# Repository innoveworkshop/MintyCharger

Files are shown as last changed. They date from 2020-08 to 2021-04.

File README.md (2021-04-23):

# MintyCharger

A complete USB-powered PP3 battery charger that fits neatly inside an Altoids
tin. To learn more please [visit the project website](https://innoveworkshop.com/product/mintycharger).

Project Logo

## Supported Batteries

This charger is capable of working with the following battery chemistries and
nominal voltages:

  - NiMH
    - 9.6V
	- 8.4V
	- 7.2V
  - Lithium
    - 7.4V

## Board Layout

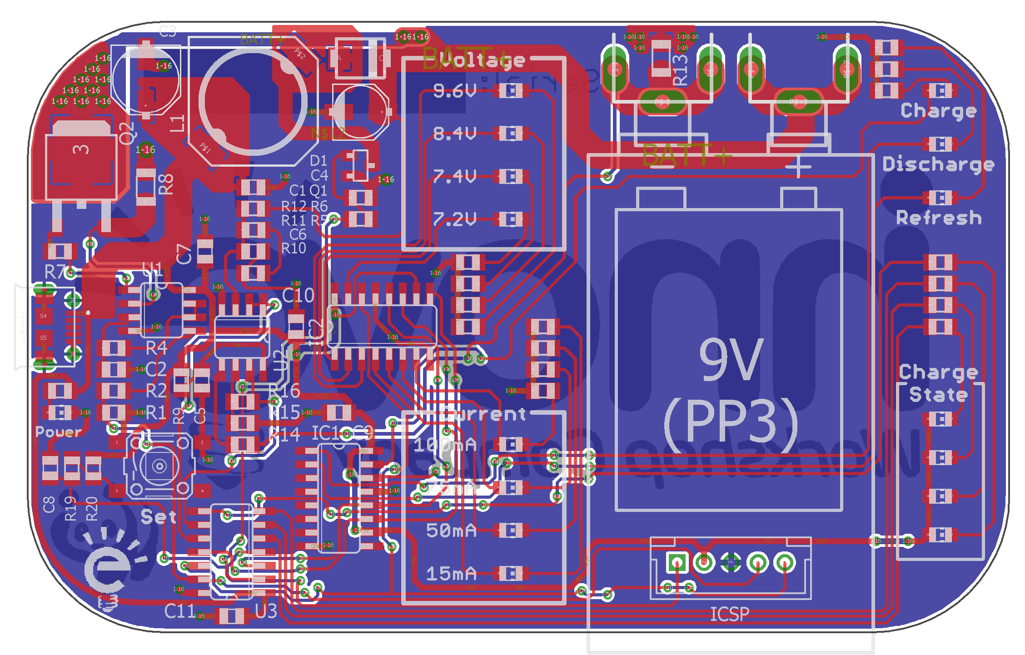
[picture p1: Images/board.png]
PCB Layout


## License

<br />This work is licensed under a <a rel="license" href="http://creativecommons.org/licenses/by-nc-sa/4.0/">Creative Commons Attribution-NonCommercial-ShareAlike 4.0 International License</a>.

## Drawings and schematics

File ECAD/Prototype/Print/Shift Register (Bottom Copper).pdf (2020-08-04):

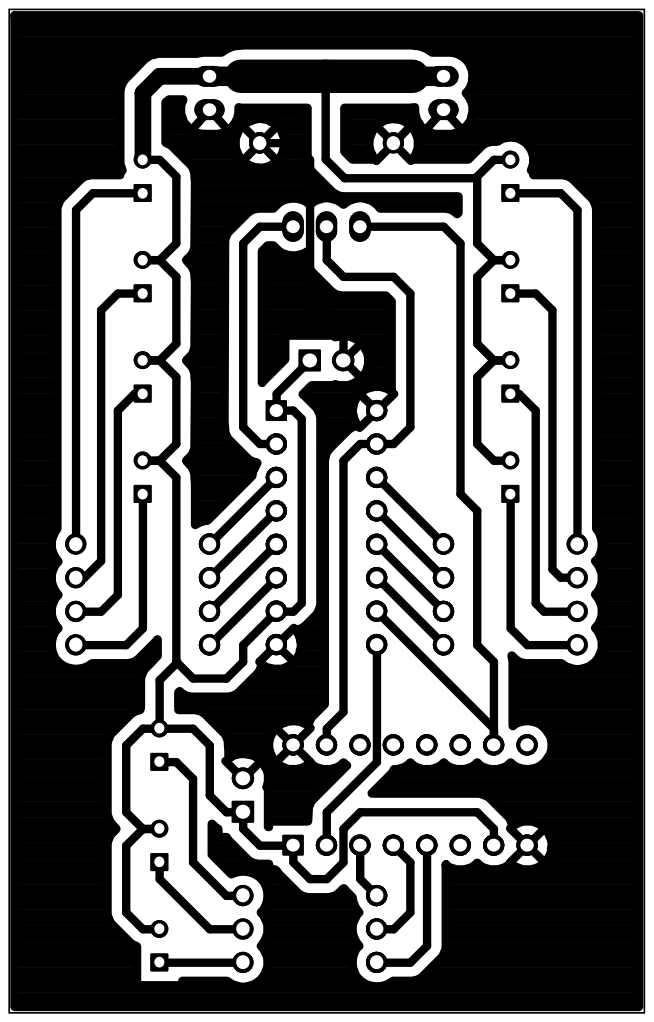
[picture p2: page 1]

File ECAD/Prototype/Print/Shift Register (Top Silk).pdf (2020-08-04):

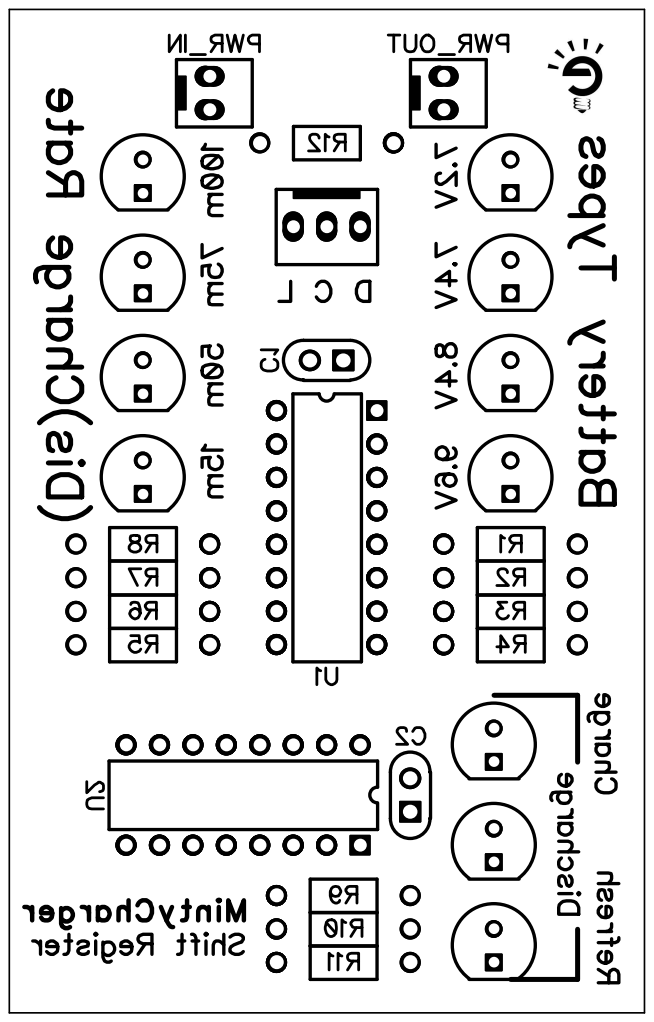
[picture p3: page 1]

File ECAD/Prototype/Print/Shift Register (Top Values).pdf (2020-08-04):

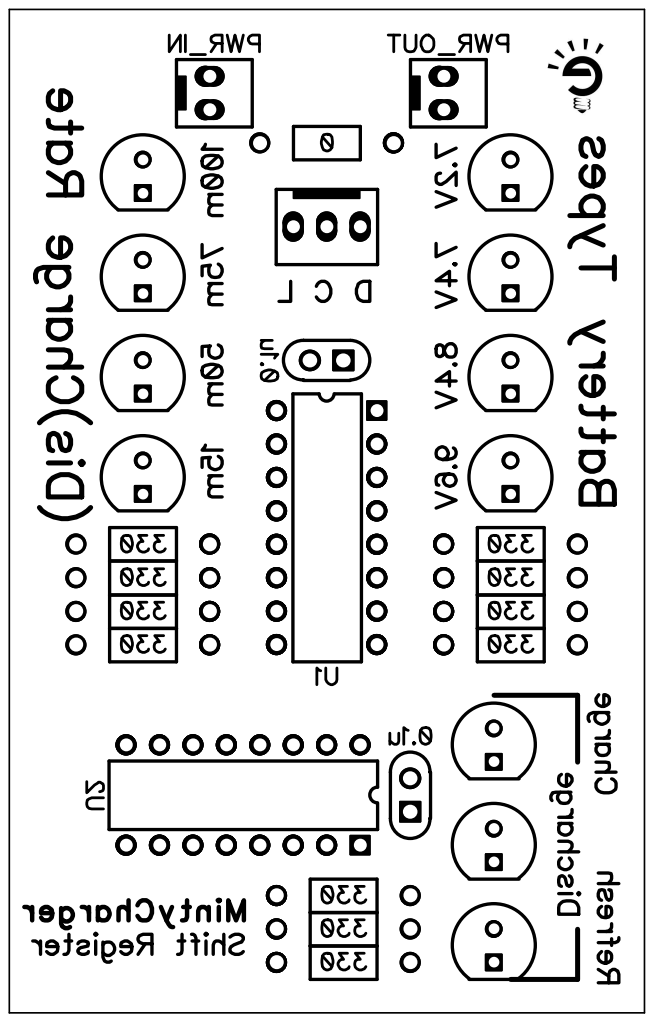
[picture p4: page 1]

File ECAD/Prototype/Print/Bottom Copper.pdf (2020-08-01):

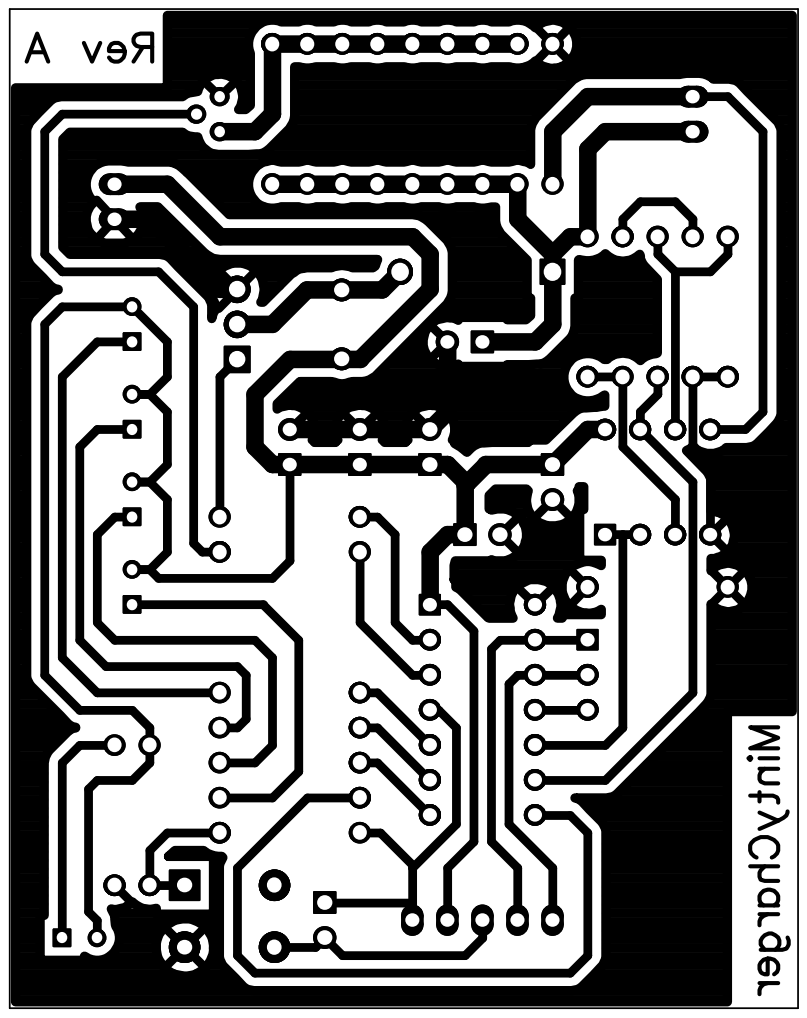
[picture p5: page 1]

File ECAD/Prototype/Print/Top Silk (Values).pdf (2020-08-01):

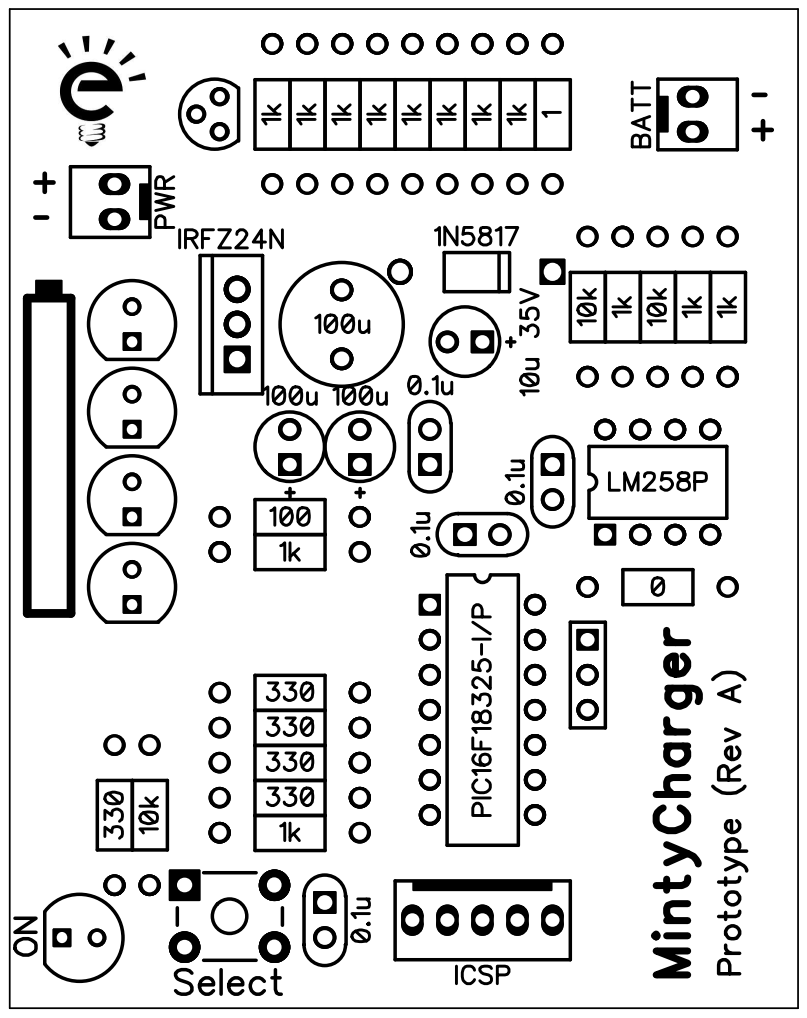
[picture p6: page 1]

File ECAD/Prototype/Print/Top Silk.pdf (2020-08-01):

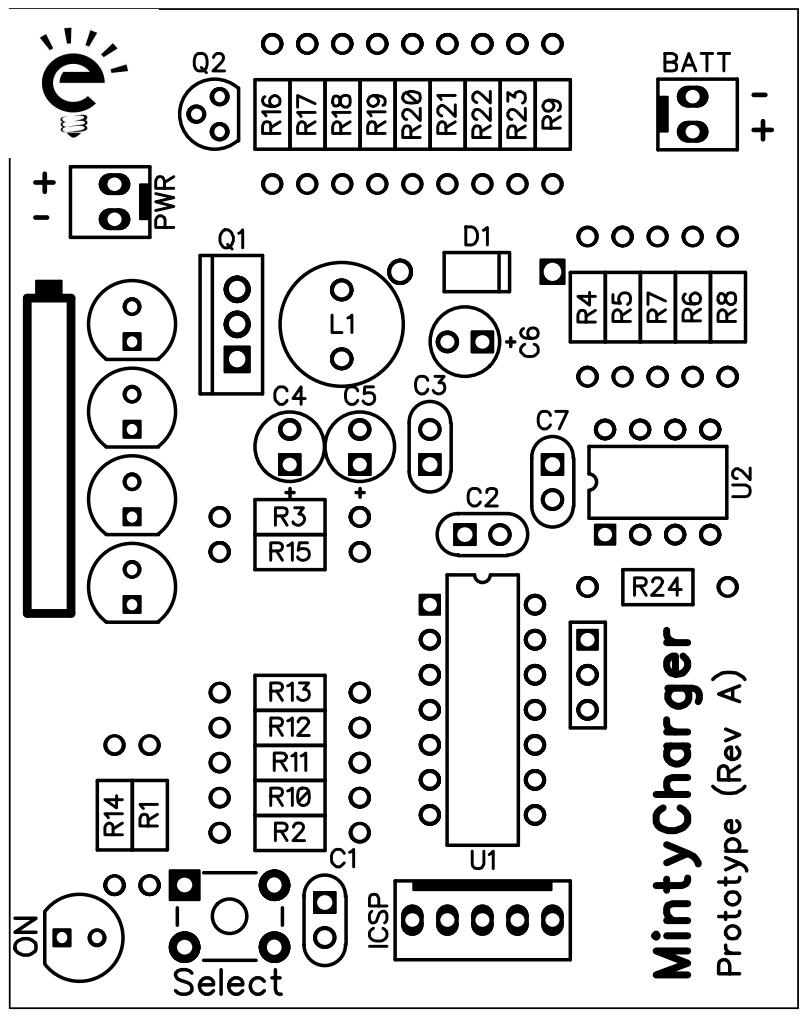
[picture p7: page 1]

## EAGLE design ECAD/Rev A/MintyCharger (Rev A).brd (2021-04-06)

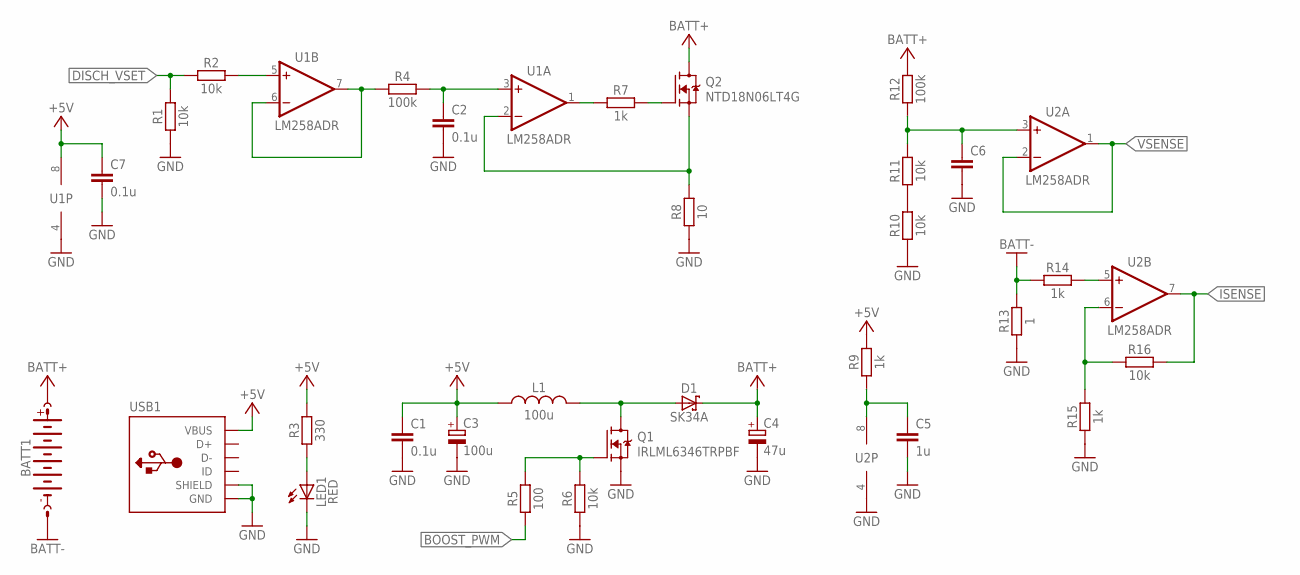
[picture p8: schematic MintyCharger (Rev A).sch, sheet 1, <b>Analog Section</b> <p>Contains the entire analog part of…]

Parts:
BATT1: KEYSTONE-590-9V
C1, C2, C7: 0.1u; C0805
C3: 100u; PANASONIC_D
C4: 47u; PANASONIC_C
C5: 1u; C0805
C6: C0805
D1: SK34A; SMA
L1: 100u; ELLCTP
LED1: RED; CHIP-LED0805
Q1: IRLML6346TRPBF; SOT23
Q2: NTD18N06LT4G; TO252
R1, R2, R6, R10, R11, R16: 10k; R0805
R3: 330; R0805
R4, R12: 100k; R0805
R5: 100; R0805
R7, R9, R14, R15: 1k; R0805
R8: 10; R1206
R13: 1; R1206
U1, U2: LM258ADR; SO08
USB1: USB-MICRO-10118194-0001LF; AMPHENOL_10118194-0001LF

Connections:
+5V: C1.1, C3.+, C7.1, L1.P$1 (1), R3.2, R9.2, U1.8 (V+), USB1.VCC (VBUS); also elsewhere on the board
BATT+: BATT1.P$+1 (+), BATT1.P$+2 (+), BATT1.P$+3 (+), C4.+, D1.C, Q2.3 (D), R12.2
BATT-: BATT1.P$-1 (-), BATT1.P$-2 (-), BATT1.P$-3 (-), R13.2, R14.1
BOOST_PWM: R5.1; also elsewhere on the board
DISCH_VSET: R1.2, R2.1; also elsewhere on the board
GND: C1.2, C2.2, C3.-, C4.-, C5.2, C6.2, C7.2, LED1.C, Q1.2 (S), R1.1, R6.1, R8.1, R10.1, R13.1, R15.1, U1.4 (V-), U2.4 (V-), USB1.GND, USB1.S1 (SHIELD), USB1.S2 (SHIELD), USB1.S3 (SHIELD), USB1.S4 (SHIELD), USB1.S5 (SHIELD), USB1.S6 (SHIELD), USB1.S7 (SHIELD), USB1.S8 (SHIELD); also elsewhere on the board
ISENSE: R16.2, U2.7 (OUT); also elsewhere on the board
unnamed: R10.2, R11.1
unnamed: C6.1, R11.2, R12.1, U2.3 (+IN)
unnamed: R15.2, R16.1, U2.6 (-IN)
unnamed: Q2.2 (S), R8.2, U1.2 (-IN)
unnamed: C2.1, R4.2, U1.3 (+IN)
unnamed: R4.1, U1.6 (-IN), U1.7 (OUT)
unnamed: R2.2, U1.5 (+IN)
unnamed: Q2.1 (G), R7.2
unnamed: R7.1, U1.1 (OUT)
unnamed: R14.2, U2.5 (+IN)
unnamed: C5.1, R9.1, U2.8 (V+)
unnamed: D1.A, L1.P$2 (2), Q1.3 (D)
unnamed: Q1.1 (G), R5.2, R6.2
unnamed: LED1.A, R3.1
VSENSE: U2.1 (OUT), U2.2 (-IN); also elsewhere on the board

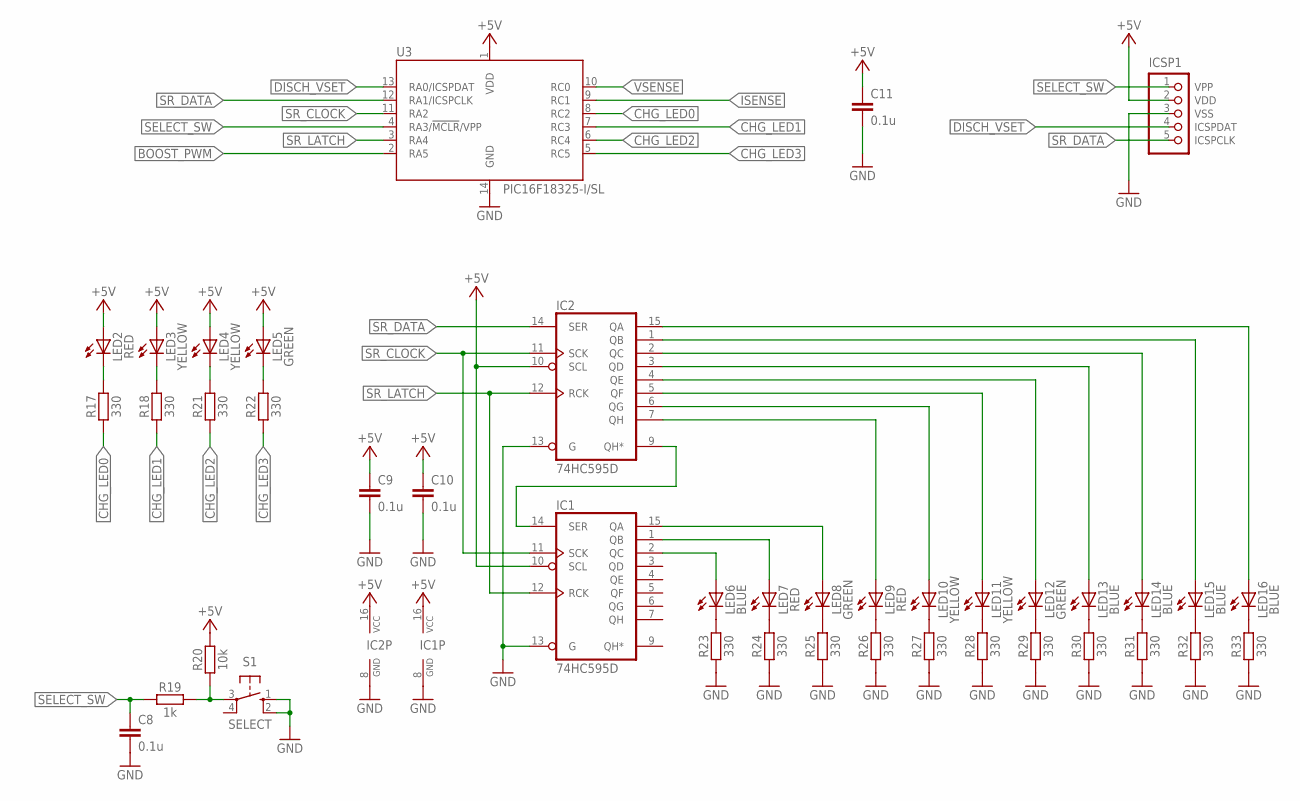
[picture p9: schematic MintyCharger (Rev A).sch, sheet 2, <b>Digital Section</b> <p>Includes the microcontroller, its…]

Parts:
C8, C9, C10, C11: 0.1u; C0805
IC1, IC2: 74HC595D; SO16
ICSP1: PIC-ICSPJST-XH; B5B-XH-A
LED2, LED7, LED9: RED; CHIP-LED0805
LED3, LED4, LED10, LED11: YELLOW; CHIP-LED0805
LED5, LED8, LED12: GREEN; CHIP-LED0805
LED6, LED13, LED14, LED15, LED16: BLUE; CHIP-LED0805
R17, R18, R21, R22, R23, R24, R25, R26, R27, R28, R29, R30, R31, R32, R33: 330; R0805
R19: 1k; R0805
R20: 10k; R0805
S1: SELECT; PTS645-SMT
U3: PIC16F18325-I/SL; SO14

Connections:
+5V: C9.1, C10.1, C11.1, IC1.10 (SCL), IC1.16 (VCC), IC2.10 (SCL), IC2.16 (VCC), ICSP1.2 (VDD), LED2.A, LED3.A, LED4.A, LED5.A, R20.2, U3.1 (VDD); also elsewhere on the board
BOOST_PWM: U3.2 (RA5); also elsewhere on the board
CHG_LED0: R17.1, U3.8 (RC2)
CHG_LED1: R18.1, U3.7 (RC3)
CHG_LED2: R21.1, U3.6 (RC4)
CHG_LED3: R22.1, U3.5 (RC5)
DISCH_VSET: ICSP1.4 (ICSPDAT), U3.13 (RA0/ICSPDAT); also elsewhere on the board
GND: C8.2, C9.2, C10.2, C11.2, IC1.8 (GND), IC1.13 (G), IC2.8 (GND), IC2.13 (G), ICSP1.3 (VSS), R23.1, R24.1, R25.1, R26.1, R27.1, R28.1, R29.1, R30.1, R31.1, R32.1, R33.1, S1.1 (S), S1.2 (S1), U3.14 (GND); also elsewhere on the board
ISENSE: U3.9 (RC1); also elsewhere on the board
unnamed: LED5.C, R22.2
unnamed: LED4.C, R21.2
unnamed: LED3.C, R18.2
unnamed: LED2.C, R17.2
unnamed: IC1.14 (SER), IC2.9 (QH*)
unnamed: LED9.C, R26.2
unnamed: LED10.C, R27.2
unnamed: LED11.C, R28.2
unnamed: LED12.C, R29.2
unnamed: LED13.C, R30.2
unnamed: LED14.C, R31.2
unnamed: LED15.C, R32.2
unnamed: LED16.C, R33.2
unnamed: R19.2, R20.1, S1.3
unnamed: LED6.C, R23.2
unnamed: LED7.C, R24.2
unnamed: LED8.C, R25.2
unnamed: IC1.15 (QA), LED8.A
unnamed: IC1.1 (QB), LED7.A
unnamed: IC1.2 (QC), LED6.A
unnamed: IC2.7 (QH), LED9.A
unnamed: IC2.6 (QG), LED10.A
unnamed: IC2.5 (QF), LED11.A
unnamed: IC2.4 (QE), LED12.A
unnamed: IC2.3 (QD), LED13.A
unnamed: IC2.2 (QC), LED14.A
unnamed: IC2.1 (QB), LED15.A
unnamed: IC2.15 (QA), LED16.A
SELECT_SW: C8.1, ICSP1.1 (VPP), R19.1, U3.4 (RA3/!MCLR!/VPP)
SR_CLOCK: IC1.11 (SCK), IC2.11 (SCK), U3.11 (RA2)
SR_DATA: IC2.14 (SER), ICSP1.5 (ICSPCLK), U3.12 (RA1/ICSPCLK)
SR_LATCH: IC1.12 (RCK), IC2.12 (RCK), U3.3 (RA4)
VSENSE: U3.10 (RC0); also elsewhere on the board

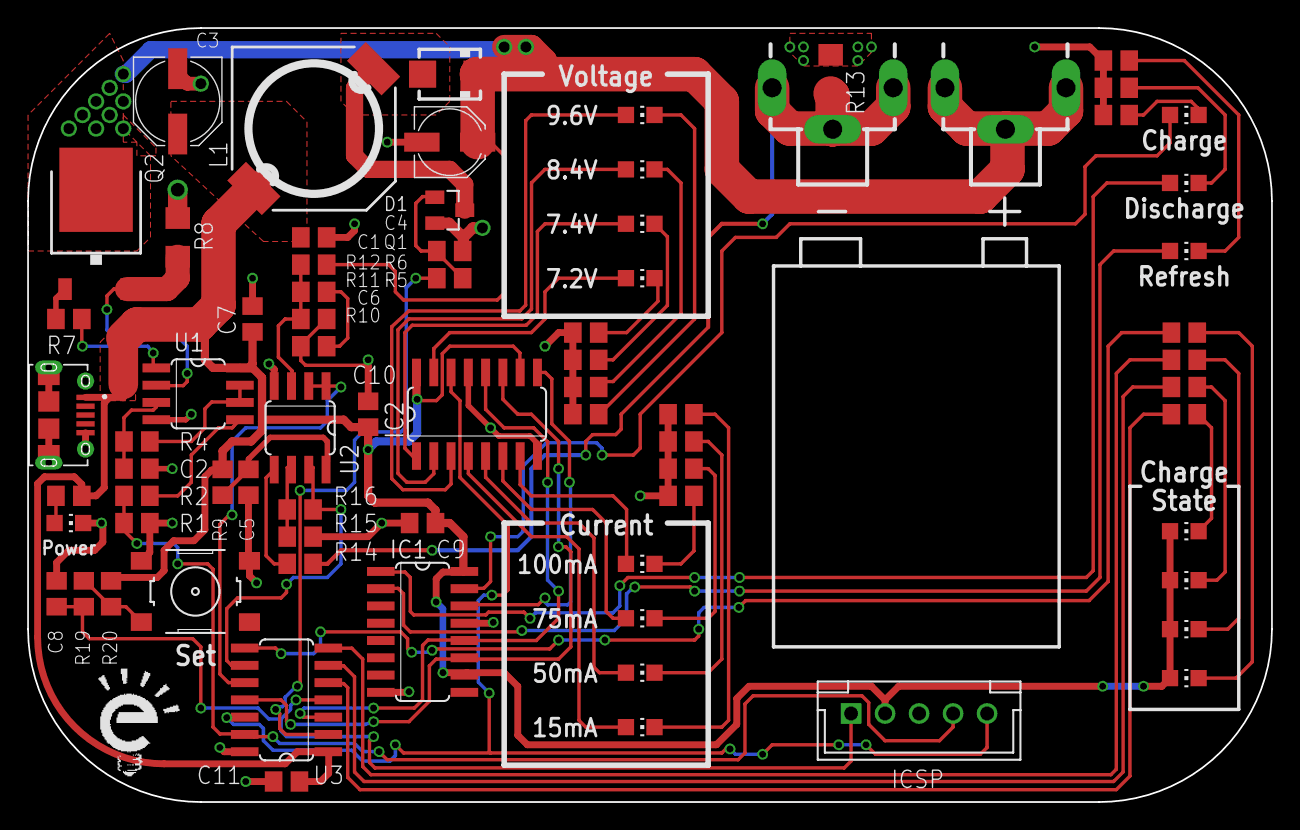
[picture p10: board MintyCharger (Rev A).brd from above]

Board: 2 copper layers, 91.4 x 56.9 mm, 74 parts (0 on the bottom side), 58 nets.

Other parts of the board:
U$1: ALTOIDSTIN-DIM

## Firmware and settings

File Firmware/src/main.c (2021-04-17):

/**
 * MintyCharger
 * A complete PP3 (9.6V, 8.4V, 7.4V, and 7.2V) NiMH charger that fits neatly
 * inside an Altoids tin.
 * 
 * @author Nathan Campos <nathan@innoveworkshop.com>
 */

#include "config.h"
#include <xc.h>
#include <pic16f18325.h>
#include <stdbool.h>
#include <stdint.h>
#include "eeprom.h"
#include "pins.h"
#include "adc.h"
#include "vreg.h"
#include "interface.h"
#include "gauge.h"
#include "load.h"
#include "refresh.h"
#include "version.h"

// Private methods.
void EnableInterrupts(void);
void DisableInterrupts(void);
void InitializeIO(void);
void InitializeFVR(void);
void InitializeADC(void);
void InitializePWM(void);
void InitializeDAC(void);
void InitializeButtonInterrupt(void);
void InitializeButtonHoldTimer(void);
void InitializeFlashingTimer(void);

/**
 * Main entry point.
 */
void main(void) {
	// Set the WDT to 4s for initializing everything.
	WDTCONbits.WDTPS = 0b01100;
	CLRWDT();
	
	// Initialize everything.
	DisableInterrupts();
	InitializeIO();
	InitializeFVR();
	InitializeADC();
	InitializePWM();
	InitializeDAC();
	InitializeButtonInterrupt();
	InitializeButtonHoldTimer();
	InitializeFlashingTimer();
	__delay_ms(100); // Give some time for stuff to stabilise.
	DisplayFirmwareInformation();
	EnableInterrupts();

	// Start the voltage regulation ADC loop.
	DisableRegulator();
	DisableLoad();
	StartNextADCReading();
	InitializeUI();

	// Reset the WDT to 256ms for normal operation and enable the flashing timer.
	WDTCONbits.WDTPS = 0b01000;
	T6CONbits.TMR6ON = 1;

	// Main application loop.
	while (true) {
		// Reset the watchdog timer.
		CLRWDT();
		
		// Add a bit of delay to make sure things are stable.
		__delay_ms(10);
		
		// Detect the battery end of charge.
		if (!IsFinishedCharging())
			DetectEndOfCharge();
		
		// Detect the load cutoff voltage and stop over discharging the battery.
		DetectLoadCutoff();
		
		// Detect if we need to go to the next part of a refresh cycle.
		DetectRefreshCycleSwitch();
	}
}

/**
 * Interrupt service routine.
 */
void __interrupt() ISR(void) {
	// ADC interrupt.
	if (PIR1bits.ADIF) {
		// Combine registers into a single 10-bit value and store it.
		uint16_t adcValue = (uint16_t)((ADRESH << 8) | ADRESL);
		StoreADCValue(adcValue);

		// Regulate the boost output voltage and current.
		RegulateBoostOutput();

		// Clear the interrupt and start the next reading cycle.
		PIR1bits.ADIF = 0;
		StartNextADCReading();
	}

	// Select button (INT) interrupt.
	if (PIR0bits.INTF) {
		// Check if the button is still pressed.
		if ((PORTA & BTN_SELECT) == 0) {
			// Restart the hold down timer.
			T1CONbits.TMR1ON = 0; // Disable the timer.
			TMR1H = 0;            // Reset the high part of the counter.
			TMR1L = 0;            // Reset the low part of the counter.
			T1CONbits.TMR1ON = 1; // Enable the timer.
		} else {
			// Check if the timer is running. Detect if it was a single click.
			if (T1CONbits.TMR1ON)
				HandleSingleButtonClick();

			// Disable the timer.
			T1CONbits.TMR1ON = 0;
		}

		// Clear the interrupt.
		PIR0bits.INTF = 0;
	}

	// Button hold timer (Timer1) interrupt.
	if (PIR1bits.TMR1IF) {
		// Check if the button is still pressed and go to the next selection.
		if ((PORTA & BTN_SELECT) == 0)
			NextConfigurationSelection();

		// Turn the timer off and clear the interrupt.
		T1CONbits.TMR1ON = 0;
		PIR1bits.TMR1IF = 0;
	}

	// Editing configuration flash timer (Timer6) interrupt.
	if (PIR2bits.TMR6IF) {
		// Blinkenlights.
		FlashCurrentEditableConfiguration();
		DisplayBatteryGauge();

		// Clear the interrupt.
		PIR2bits.TMR6IF = 0;
	}
}

/**
 * Sets up all the I/O pins for the application.
 */
void InitializeIO(void) {
	// Setup digital inputs.
	TRISA = BTN_SELECT;
	TRISC = VSENSE + ISENSE;

	// Disable ALL analog inputs on PORTA.
	ANSELA = 0;

	// Setup pull-ups.
	WPUA = 0;
	WPUC = 0;

	// Setup open-drains.
	ODCONA = 0;
	ODCONC = CHG_LED0 + CHG_LED1 + CHG_LED2 + CHG_LED3;

	// Set all the outputs to LOW.
	LATA = 0;
	LATC = 0;
}

/**
 * Sets up the fixed voltage reference.
 */
void InitializeFVR(void) {
	// Setup FVR outputs.
	FVRCONbits.ADFVR = 0b10;  // 2.048V ADC reference.
	FVRCONbits.CDAFVR = 0b01; // 1.024V DAC and Comparator reference.
	
	// Make it work.
	FVRCONbits.FVREN = 1;     // Enable the reference module.
	FVRCONbits.TSEN = 0;      // Disable the temperature indicator.
}

/**
 * Sets up the ADCs and their associated pins.
 */
void InitializeADC(void) {
	// Setup pins for the ADC.
	ANSELC = VSENSE + ISENSE;

	// Setup the ADC module.
	ADCON1bits.ADFM = 1;            // Right justified.
	ADCON1bits.ADCS = 0b010;        // Fosc/32 (1us @ 32MHz)
	ADCON1bits.ADNREF = 0;          // Negative reference is Vss.
	ADCON1bits.ADPREF = 0b11;       // Positive reference is connected to the FVR.
	ADCON0bits.CHS = ADC_CH_VSENSE; // Set the VSENSE pin as the default channel.
	ADCON0bits.ADON = 1;            // Turn the ADC module ON.
	PIE1bits.ADIE = 1;              // Enable the ADC interrupt.
}

/**
 * Sets up the PWM module and assigns the output pin.
 */
void InitializePWM(void) {
	// Unlock the PPS and set the PWM output pin.
	PPSLOCK = 0x55;
	PPSLOCK = 0xAA;
	PPSLOCKbits.PPSLOCKED = 0; // Unlock the PPS.
	RA5PPSbits.RA5PPS = 0b10;  // Set PWM5 output to RA5.
	PPSLOCK = 0x55;
	PPSLOCK = 0xAA;
	PPSLOCKbits.PPSLOCKED = 1; // Lock the PPS.

	// Setup the PWM module.
	PWM5CONbits.PWM5POL = 0;   // Pulses are positive.
	PR2 = 0x3F;                // 78.12kHz @ 20MHz
	PWMTMRSbits.P5TSEL = 0b01; // Use Timer2.
	PWM5DCL = 0;               // Clear the duty cycle registers.
	PWM5DCH = 0;

	// Setup the Timer2 for PWM operation.
	PIE1bits.TMR2IE = 0;       // Disable its interrupt.
	T2CONbits.T2CKPS = 0;      // Prescaler set to 1.
	T2CONbits.TMR2ON = 1;      // Enable the timer.

	// Wait for Timer2 to be ready.
	while (TMR2IF == 0);

	// Enable the PWM and unlock the slew rate for the pin.
	PWM5CONbits.PWM5EN = 1;
	SLRCONAbits.SLRA5 = 0;
}

/**
 * Sets up the DAC for the electronic DC load.
 */
void InitializeDAC(void) {
	// Setup voltage sources.
	DACCON0bits.DAC1PSS = 0b10; // Positive reference is connected to the FVR.
	DACCON0bits.DAC1NSS = 0;    // Negative reference is Vss.
	
	// Enable the DAC and reset its output.
	DACCON0bits.DAC1EN = 1;
	DACCON1bits.DAC1R = 0;
	
	// Enable the DAC output to RA0.
	DACCON0bits.DAC1OE = 1;
}

/**
 * Initializes the interrupt used to detect button presses.
 */
void InitializeButtonInterrupt(void) {
	// Unlock the PPS and set the Select button as a source for the INT interrupt.
	PPSLOCK = 0x55;
	PPSLOCK = 0xAA;
	PPSLOCKbits.PPSLOCKED = 0;   // Unlock the PPS.
	INTPPSbits.INTPPS = 0b00011; // Set RA3 as an input to INT.
	PPSLOCK = 0x55;
	PPSLOCK = 0xAA;
	PPSLOCKbits.PPSLOCKED = 1;   // Lock the PPS.
	INTCONbits.INTEDG = 0;       // Trigger on the falling edge.
	PIE0bits.INTE = 1;           // Enable the INT interrupt.
}

/**
 * Initializes the timer that will be used to determine a button hold.
 */
void InitializeButtonHoldTimer(void) {
	// Setup the Timer1 as a button hold timer of ~2s.
	T1CONbits.TMR1ON = 0;     // Disable the timer.
	T1CONbits.TMR1CS = 0b11;  // LFINTOSC as the clock source.
	T1CONbits.T1CKPS = 0b00;  // Prescaler set to 1.
	T1GCONbits.TMR1GE = 0;    // Disable gating. Will run like any other timer.
	PIE1bits.TMR1IE = 1;      // Enable its interrupt.
}

/**
 * Initializes the timer that will be used to flash the configuration lights
 * when configuring the charger.
 */
void InitializeFlashingTimer(void) {
	// Setup Timer6 as the timer for blinkenlights.
	T6CONbits.TMR6ON = 0;       // Disable the timer.
	T6CONbits.T6CKPS = 0b11;    // Prescaler set to 64.
	T6CONbits.T6OUTPS = 0b1111; // Postscaler set to 16.
	PR6 = 0xFF;                 // Period set to maximum.
	PIE2bits.TMR6IE = 1;        // Enable the timer interrupt.
}

/**
 * Enables global interrupts.
 * @remark You should set the interrupts of individual peripherals yourself.
 *         This function will only enable them globally.
 */
void EnableInterrupts(void) {
	INTCONbits.GIE = 1;
	INTCONbits.PEIE = 1;
}

/**
 * Disables global interrupts.
 * @remark You should set the interrupts of individual peripherals yourself.
 *         This function will only disable them globally.
 */
void DisableInterrupts(void) {
	INTCONbits.GIE = 0;
	INTCONbits.PEIE = 0;
}

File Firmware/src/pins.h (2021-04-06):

/* 
 * pins.h
 * Pin definitions.
 * 
 * @author Nathan Campos <nathan@innoveworkshop.com>
 */

#ifndef PINS_H
#define	PINS_H

//                           16F18325
//                         +----------+
// LED Shift Register DAT -|RA0    RC0|- Voltage Sense - ANC0
// LED Shift Register CLK -|RA1    RC1|- Current Sense - ANC1
// LED Shift Register LAT -|RA2    RC2|- Charge LED 0
// Select Switch          -|RA3    RC3|- Charge LED 1
// Discharge Enable       -|RA4    RC4|- Charge LED 2
// Boost DC/DC PWM - PWM1 -|RA5    RC5|- Charge LED 3
//                         +----------+


// Pin definitions.
#define DISCH_VSET 1         // RA0
#define SR_DATA    (1 << 1)  // RA1
#define SR_CLOCK   (1 << 2)  // RA2
#define BTN_SELECT (1 << 3)  // RA3
#define SR_LATCH   (1 << 4)  // RA4
#define BOOST_PWM  (1 << 5)  // RA5
#define VSENSE     1         // RC0
#define ISENSE     (1 << 1)  // RC1
#define CHG_LED0   (1 << 2)  // RC2
#define CHG_LED1   (1 << 3)  // RC3
#define CHG_LED2   (1 << 4)  // RC4
#define CHG_LED3   (1 << 5)  // RC5

// Analog channel definitions.
#define ADC_CH_VSENSE 0b10000
#define ADC_CH_ISENSE 0b10001

#endif	/* PINS_H */

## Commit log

2020-08-01 Created a simple home-etched PCB prototype to start working on the firmware
2020-08-01 Added the clock frequency to the configurations header so that it can be used by timer functions
2020-08-02 Organized all the voltage regulation stuff
2020-08-02 Current regulation added
2020-08-02 Measuring the battery voltage in a differential manner
2020-08-02 Added some functions to get the battery voltage and current as floats
2020-08-03 Fixed the battery measurement and improved the output regulation
    [vreg.c]
2020-08-03 Added the ability to start and stop the voltage regulator
2020-08-04 Minor repositioning of a GND point
2020-08-04 Finished the prototype shift register module schematic
2020-08-04 Renumbered the shift register prototype module RefDes
2020-08-04 Finished the shift register prototype module PCB
2020-08-04 Added shift register prototype laser etch PDFs
2020-08-05 Moved the pin mapping graphics to the appropriate header file
2020-08-05 Removed all the MSSP code that didn't work as expected
    [main.c]
2020-08-05 Setting the LEDs according to the selected settings
2020-08-06 Detecting a button hold
2020-08-06 Put on a little show upon reset
    [interface.c, main.c]
2020-08-10 Finished the Rev A schematic
    [MintyCharger (Rev A).sch]
2020-08-12 Finished the board layout of RevA
    [MintyCharger (Rev A).brd, MintyCharger (Rev A).sch]
2020-08-12 Added more battery types to the README
2021-04-06 Moved all the firmware code to a new directory and made the pre-prototype code work in the Rev A board
2021-04-06 ECAD - Minor changes to the Rev A files
    [MintyCharger (Rev A).brd, MintyCharger (Rev A).sch]
2021-04-07 Firmware - Detecting end-of-charge and exposing a whole bunch of states from the voltage regulator module
    Ref T35
2021-04-07 Firmware - Created a function to get the battery cell voltage Ref T35
2021-04-07 Firmware - Displaying a charge state gauge Ref T35
2021-04-08 Fixed the bug where GetBatteryVoltage always returned 0
    Fixes T37
    [vreg.c]
2021-04-08 Fixed the way the battery voltage was calculated
    [vreg.c]
2021-04-08 Firmware - Blinking to indicate the current charging state
    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
2021-04-08 Firmware - Changed the voltage regulation algorithm a bit
2021-04-08 Firmware - Fixed the indentation of the whole project
    [interface.c, main.c, vreg.c]
2021-04-08 Firmware - Detecting battery disconnection
    Ref T38
2021-04-09 Firmware - Trying (and failling) to detect the insertion of a battery
    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
    [vreg.c]
2021-04-09 Firmware - Removed the battery insertion detection function
    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
2021-04-09 Firmware - Minor change to the way the battery gauge is calculated
    Ref T35 T38
2021-04-09 Firmware - Start charging by clicking the select button
    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
2021-04-09 Firmware - Detecting the end of a charge
    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
2021-04-10 Firmware - Comitting configuration changes to the voltage regulator
    Ref T42
2021-04-10 Firmware - Making sure the gauge is blank while selecting a configuration
    Fixes T43
    [interface.c]
2021-04-10 Firmware - Fixed the charging current setting values
    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
    [interface.c]
2021-04-10 Firmware - Fixed the way the configuration LEDs were being set
    Fixes T44
    [interface.c, main.c]
2021-04-12 Firmware - Saving configuration to EEPROM
    Fixes T41, T42
    [interface.c]
2021-04-12 Firmware - Start charging as soon as the user finishes setting up the configuration
2021-04-12 Firmware - Converted spaces to tabs (MPLAB X reset for some reason)
    [interface.c, vreg.c]
2021-04-12 Firmware - Minor change to the slew rate of the PWM pin
2021-04-13 Firmware - Improved end of charge detection by getting the mean current
2021-04-13 Firmware - Changed the number of current mean cycles
2021-04-13 Firmware - Setting the electronic load current and enabling/disabling it
    Ref T39
2021-04-13 Firmware - Implemented the load in the interface and fixed a little bug in the configuration selection
    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
    [interface.c]
2021-04-13 Firmware - Reorganized all of the ADC-related stuff into its own module
    Ref T39, T35
2021-04-14 Firmware - Fixed a stack overflow warning
    Apparently XC8 isn't inlining my functions.
    [interface.c]
2021-04-14 Firmware - Fixed a bug where the regulators and the load would be active together
    Apparently you can't have source file global variables with the same
    name in another source file.
    Fixes T47
    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
    [interface.c, vreg.c]
2021-04-14 Firmware - Implemented the electronic load voltage cutoff detection
    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
2021-04-14 Firmware - Greatly improved the battery gauge
    Fixes T48, T39
    [adc.c, vreg.c]
2021-04-16 Firmware - Started implementing battery refreshing
    Ref T40
2021-04-16 Firmware - Showing the current cycle of a battery refresh
    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
2021-04-16 Firmware - Corrected a couple of typos
2021-04-16 Firmware - Fixed a stack overflow caused by the refresh routines
    Fixes T40
    [interface.c, vreg.c]
2021-04-17 Firmware - Fixed some typos
    [main.c]
2021-04-17 Firmware - Decreased the gauge LED flashing frequency
    Fixes T50
2021-04-17 Firmware - Implemented a way to know the version of the firmware
    Fixes T45
    [main.c]
2021-04-17 Firmware - Enabled the watchdog timer
    Fixes T36
    [main.c]
2021-05-07 Fixed a bug where the shift registers would get out of sync on startup
    Fixes T52
    [interface.c]
